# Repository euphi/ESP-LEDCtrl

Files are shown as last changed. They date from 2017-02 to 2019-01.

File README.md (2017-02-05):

# ESP-LEDCtrl
LED Strip Controller (2x RGB, 1 White) with ESP8266 Homie (MQTT).
Display support (SSD1306 OLED) is work in progress.

## How to Build
  * If not already installed, install Platformio
    * See http://docs.platformio.org/en/latest/installation.html for instructions
    
  * Clone LEDCtrl + necessary libraries into a directory
    * `git clone https://github.com/euphi/ESP-LEDCtrl.git`
    * `git clone https://github.com/marvinroger/homie-esp8266.git`
    * `git clone https://github.com/euphi/HomieNodeCollection.git`
    * `git clone https://github.com/euphi/esp8266-oled-ssd1306.git`
    
  * Link libs into the ESP-LEDCtrl lib directory:
    * `cd ESP-LEDCtrl/lib`
    * `ln -s ../../homie-esp8266 .`
    * `ln -s ../../HomieNodeCollection .`
    * `ln -s ../../esp8266-oled-ssd1306 .`
    * `cd ..`
  
  * Run platformio
    * Ensure working directory is ESP-LEDCtrl and run `pio run` 
    * To upload, use `pio run --target upload`
    
## Outlook
  * Display support
  * touch controller support
  * Support for "set temperature", so it can be used as thermostat.

## Hardware
  * There is a kicad project with a PCB for two RGB outputs and one white channel in the [PCB subdirectory](doc/PCB)
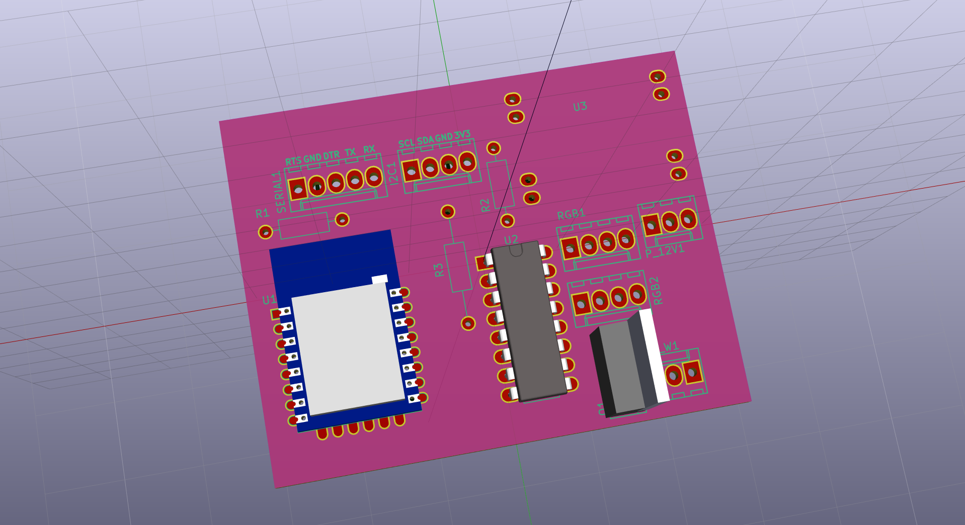
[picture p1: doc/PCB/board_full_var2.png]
3D Rendering
  * 
  * This PCB does not use any SMD parts, so it can easily be built and soldered at home (I created and etched  it with "toner transfer", then soldered the parts).
  * The RGB output uses an ULN2003A as amplifier. This is a Bipolar device with limited power, so don't drive LED strips with it without an RGB signal amplifier.
    * Example signal amplifier on [Amazon](https://www.amazon.de/gp/product/B00E4GVUMS)

  * The white channel uses a FET as driver, so you can drive white LED strips.
  * I2C is available on board. Till now, I used it to connect a HTU21 temperature+humidity sensor to it. I will add a touch controller to control the LEDs locally.
  * Serial Programming Interface available. Auto-Reset into flash mode possible with esptool / platformio using the "ck"-reset method (Connect DTR to GPIO0, RTS to Reset)
  * BOM:
    * ESP-12F (Ai-Thinker) (or ESP-12E)
    * ULN 2003
    * P16NF06L
    * DCDC-Converter (Adjustable, set to 12V -> 3,3V) (DAOKAI® 10PCS Standard Stromversorgungsmodul Adjustable Step down 3A DC DC Converter 1pc New)
    * 3x 1/4 W Resistor (Pull-Up/Down; I used 3,16kΩ)
    * Molex 4 Pin Connectors
    * Molex 3 Pin Connectors
    * 2mm Pin-Header to solder the ESP-12E
    * 2,54mm Pin-Header for Serial/Programming interface (use "ck"-Reset method for esptool).

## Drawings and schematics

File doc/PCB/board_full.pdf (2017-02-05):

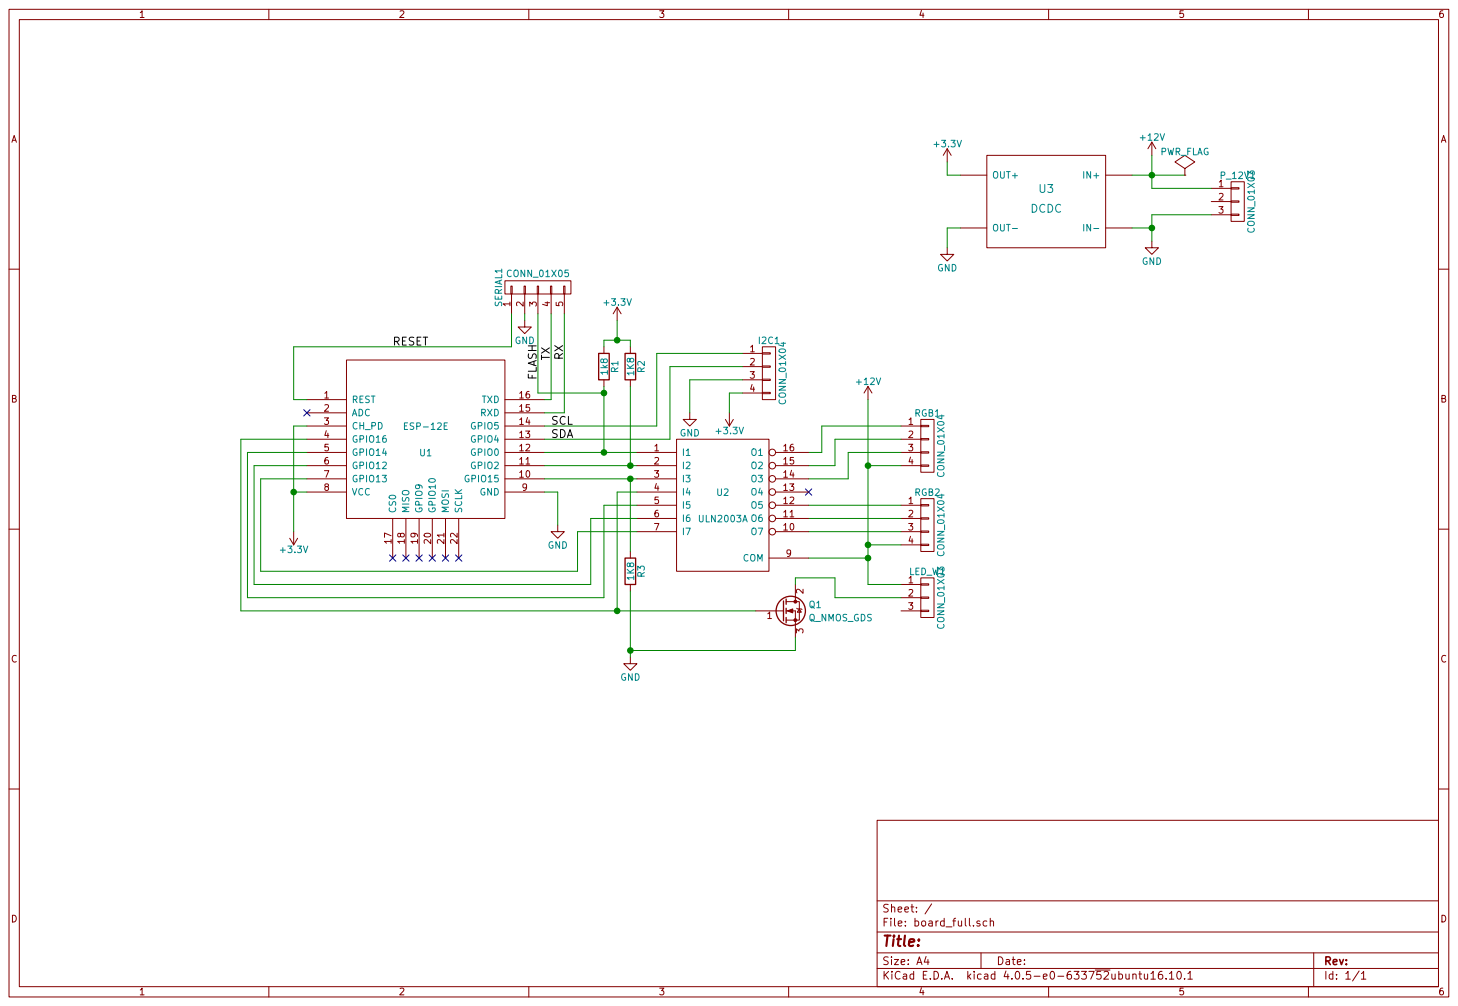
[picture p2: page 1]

2 | +12V TXRX

I4 4
I5 5
I6 6 | 2

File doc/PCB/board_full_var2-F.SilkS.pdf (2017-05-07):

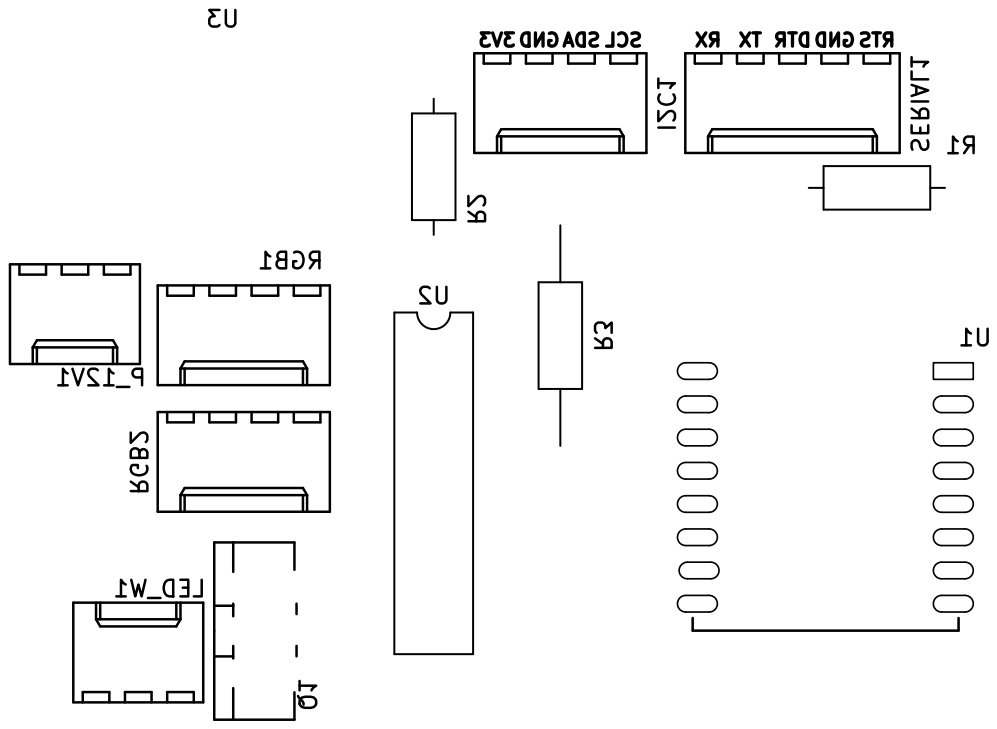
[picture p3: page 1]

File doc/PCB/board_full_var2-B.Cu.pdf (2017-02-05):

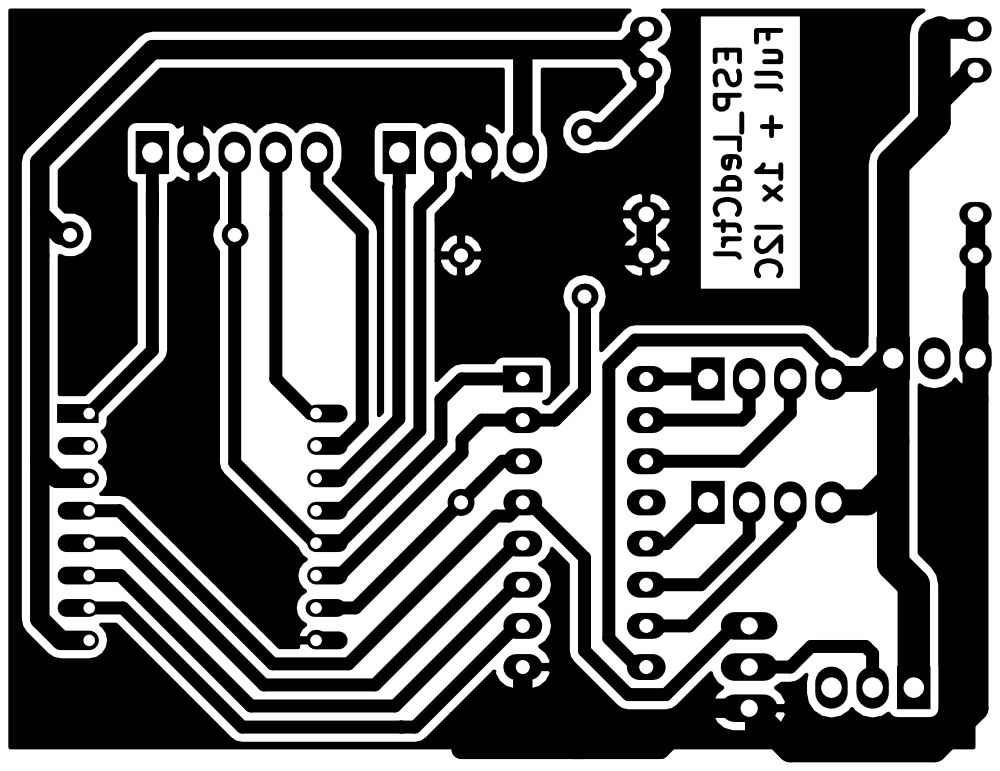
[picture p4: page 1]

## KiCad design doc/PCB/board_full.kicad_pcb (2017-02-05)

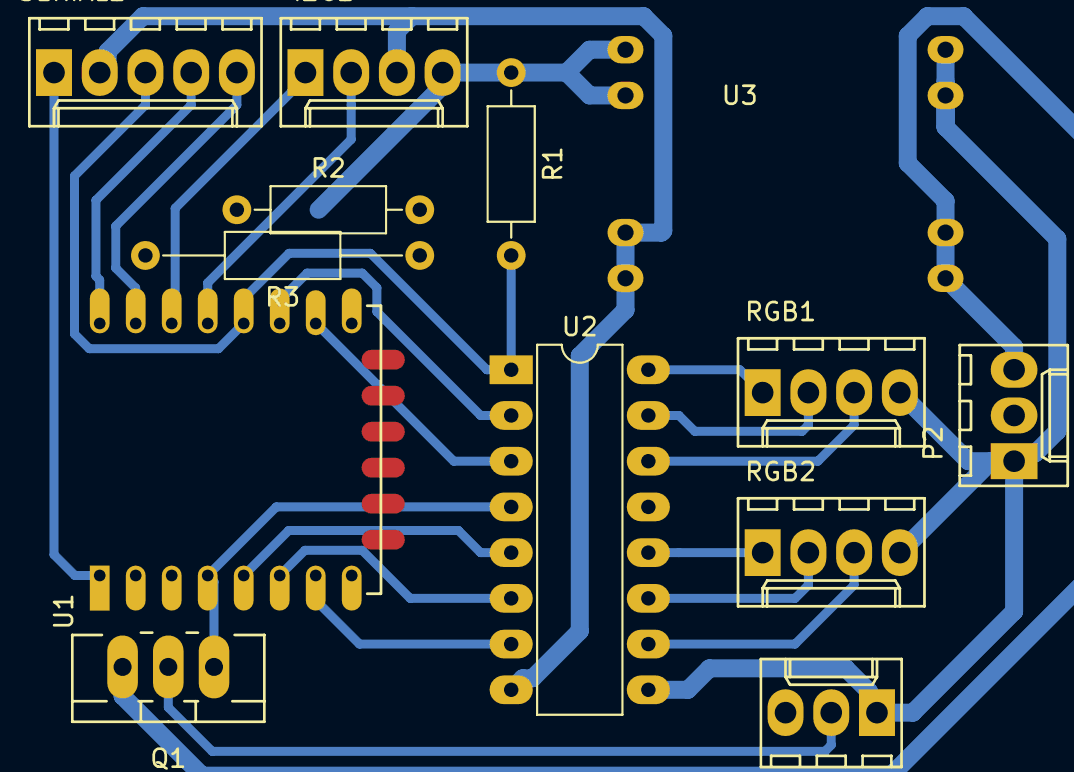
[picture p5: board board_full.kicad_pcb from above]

Board: 2 copper layers, 13 parts (0 on the bottom side), 22 nets.

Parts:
I2C1: CONN_01X04; Molex_KK-6410-04_04x2.54mm_Straight
P1, P2: CONN_01X03; Molex_KK-6410-03_03x2.54mm_Straight
Q1: Q_NMOS_GDS; TO-220_Neutral123_Vertical_LargePads
R1: 1k8; R_Axial_DIN0207_L6.3mm_D2.5mm_P10.16mm_Horizontal
R2: 1K8; R_Axial_DIN0207_L6.3mm_D2.5mm_P10.16mm_Horizontal
R3: 1K8; R_Axial_DIN0207_L6.3mm_D2.5mm_P15.24mm_Horizontal
RGB1, RGB2: CONN_01X04; Molex_KK-6410-04_04x2.54mm_Straight
SERIAL1: CONN_01X05; Molex_KK-6410-05_05x2.54mm_Straight
U1: ESP-12E
U2: ULN2003A; DIP-16_W7.62mm_LongPads
U3: DCDC

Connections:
+3V3: I2C1.4, R1.1, R2.1, U1.3, U1.8, U3.3
+12V: P1.1, P2.1, RGB1.4, RGB2.4, U2.9, U3.1
/FLASH: R1.2, SERIAL1.3, U1.12, U2.1
/RESET: SERIAL1.1, U1.1
/RX: SERIAL1.5, U1.15
/SCL: I2C1.1, U1.14
/SDA: I2C1.2, U1.13
/TX: SERIAL1.4, U1.16
GND: I2C1.3, P2.3, Q1.3, R3.2, SERIAL1.2, U1.9, U2.8, U3.2, U3.4
unnamed: P1.2, Q1.2
unnamed: Q1.1, U1.4, U2.4
unnamed: R2.2, U1.11, U2.2
unnamed: R3.1, U1.10, U2.3
unnamed: RGB1.1, U2.16
unnamed: RGB1.2, U2.15
unnamed: RGB1.3, U2.14
unnamed: RGB2.1, U2.12
unnamed: RGB2.2, U2.11
unnamed: RGB2.3, U2.10
unnamed: U1.5, U2.5
unnamed: U1.6, U2.6
unnamed: U1.7, U2.7

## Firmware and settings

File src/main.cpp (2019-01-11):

/*
 * main.cpp
 *
 *  Created on: 06.05.2016
 *      Author: ian
 */

#include <Homie.h>
#include <RGBWNode.h>
#include <SensorNode.h>
#include <LoggerNode.h>


/* includes for Libraries, so platformio can find them */
//#include <Wire.h>
//#include <Sensors.h>

//#include <InputController.h>

#include <SSD1306.h>

#include "buildnumber.h"
#define FW_NAME "LED-2x_Thermo_Ctrl"
#define FW_VERSION "1." COMMIT_COUNTER "." BUILD_NUMBER

/* Magic sequence for Autodetectable Binary Upload */
const char *__FLAGGED_FW_NAME = "\xbf\x84\xe4\x13\x54" FW_NAME "\x93\x44\x6b\xa7\x75";
const char *__FLAGGED_FW_VERSION = "\x6a\x3f\x3e\x0e\xe1" FW_VERSION "\xb0\x30\x48\xd4\x1a";
/* End of magic sequence for Autodetectable Binary Upload */

RGBWNode rgb("LED", 14, 15, 16, RGBWNode::NOPIN);
RGBWNode w1("LED_W1", RGBWNode::NOPIN,RGBWNode::NOPIN,RGBWNode::NOPIN, 0);
RGBWNode w2("LED_W2", RGBWNode::NOPIN,RGBWNode::NOPIN,RGBWNode::NOPIN, 2);

SensorNode sensor;

void setup() {
	Homie_setFirmware(FW_NAME, FW_VERSION);
	Homie.disableResetTrigger();
	Homie.disableLedFeedback();
	Serial.begin(74880);
	Serial.flush();
	Serial.println("\nSetup");
	Serial.flush();
	Wire.begin(SDA, SCL);
	//Homie.setLoggingPrinter(&display);
	Homie.setLoggingPrinter(&Serial);
	LN.setLoglevel(LoggerNode::DEBUG);
	Homie.setup();
}

void loop() {
	Homie.loop();
}

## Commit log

2017-02-05 Created PCB in Kicad and added to doc directory
    - this includes a change to main.cpp because of change in PIN usage for white LED
    [board_full.dsn, board_full.kicad_pcb, board_full.sch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]
2017-02-05 Changed symlinks to real files ... 'doh.
    [board_full.dsn, board_full.kicad_pcb, board_full.sch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]
2017-02-05 Update readme.md: Add example PCB
2017-02-05 Added resistors to BoM and added info about serial interface
2017-02-05 Added PDF of example schematics
2017-05-07 Updates to hardware (PCB)
    [board_full.sch, board_full_var2.kicad_pcb]
2017-05-16 Enable travis CI + change to example PCB
    [board_full.sch]
